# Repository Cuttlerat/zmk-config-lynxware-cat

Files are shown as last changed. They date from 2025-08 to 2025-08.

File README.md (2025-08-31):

# Lynxware Cat
[Lynxware Cat](https://www.lynxware.org/) is an open-source input device designed for creating flexible and customizable control solutions, supporting keyboard, mouse, joystick, and gyroscope interfaces.

This repository contains a modified build of Lynxware Cat v0.30.

Summary of notable changes:
- Added wireless communication using Nordic ESB via dongle.
- Migrated hardware target from BPI Leaf to Nordic nRF52840 (Nice!Nano v2 clone).
- Replaced mouse sensor with PMW3610.
- Ported firmware to ZMK.

For the complete list of changes, see the [CHANGELOG](./docs/CHANGELOG.md).

## Images

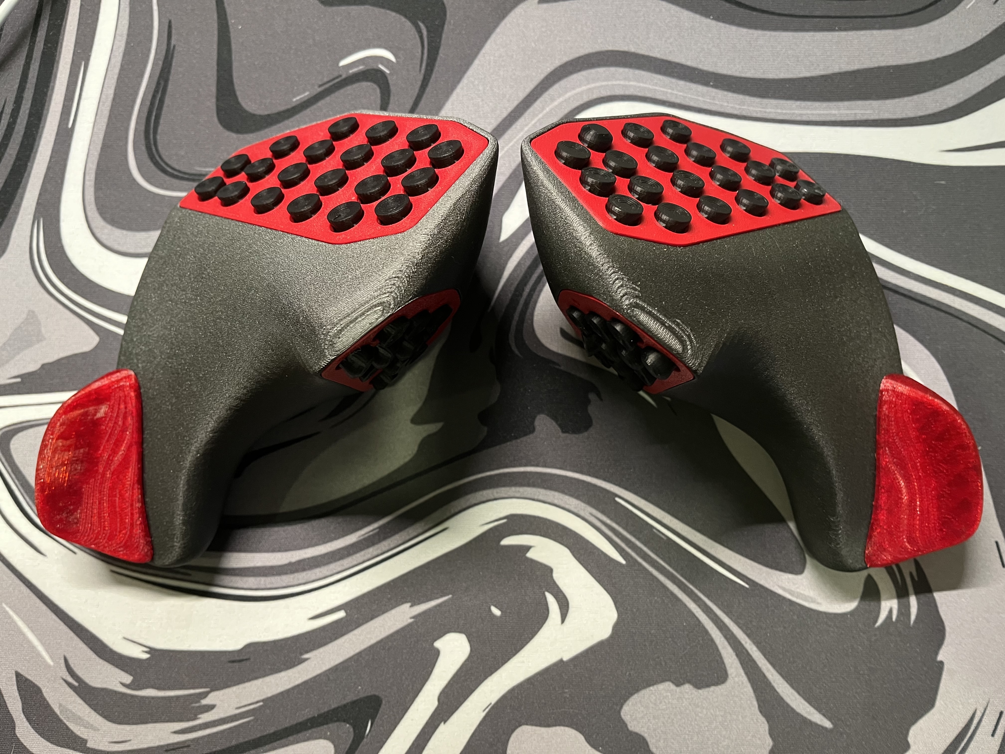
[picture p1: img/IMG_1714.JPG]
Lynxware Cat


More images are available in the [img](./img) directory.

## Keymap

<details>
<summary>Default layer</summary>

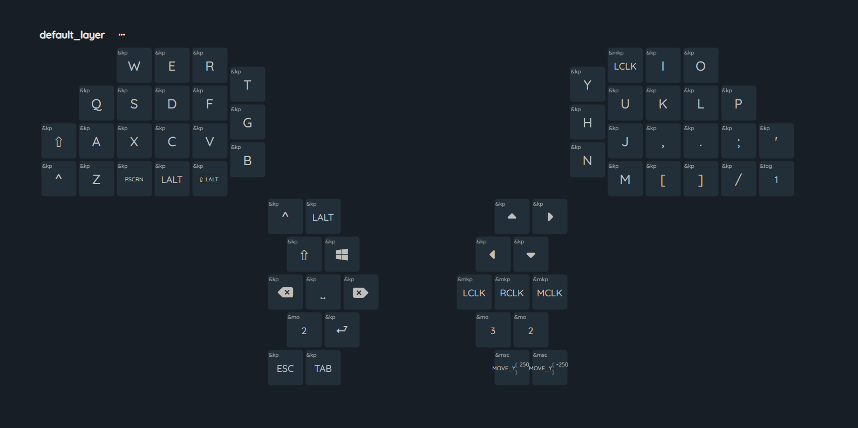
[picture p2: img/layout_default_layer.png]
Default layer


</details>

<details>
<summary>Numbers layer</summary>

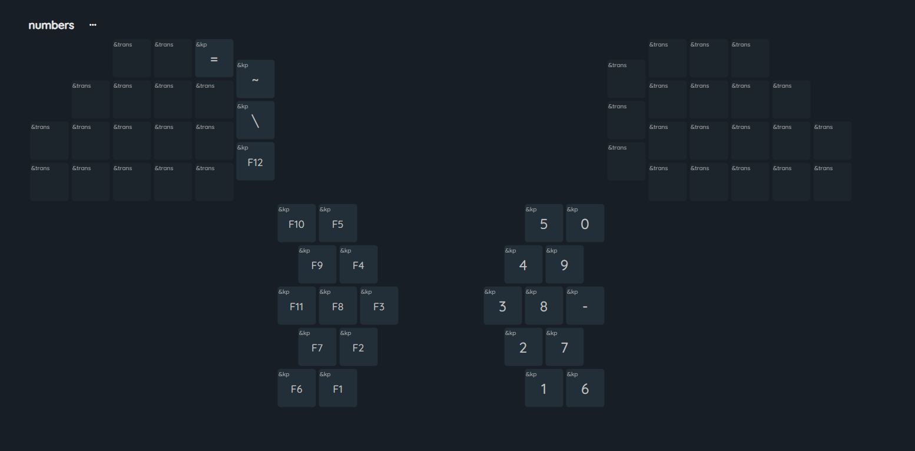
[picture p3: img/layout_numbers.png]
Numbers layer


</details>

<details>
<summary>Gaming layer</summary>

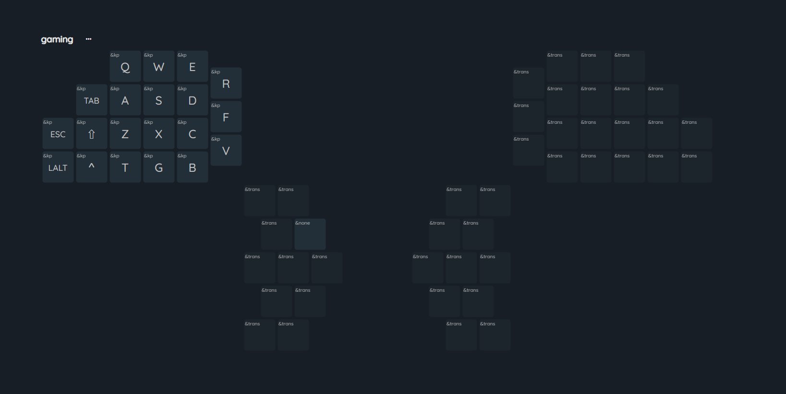
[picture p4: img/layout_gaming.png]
Gaming layer


</details>

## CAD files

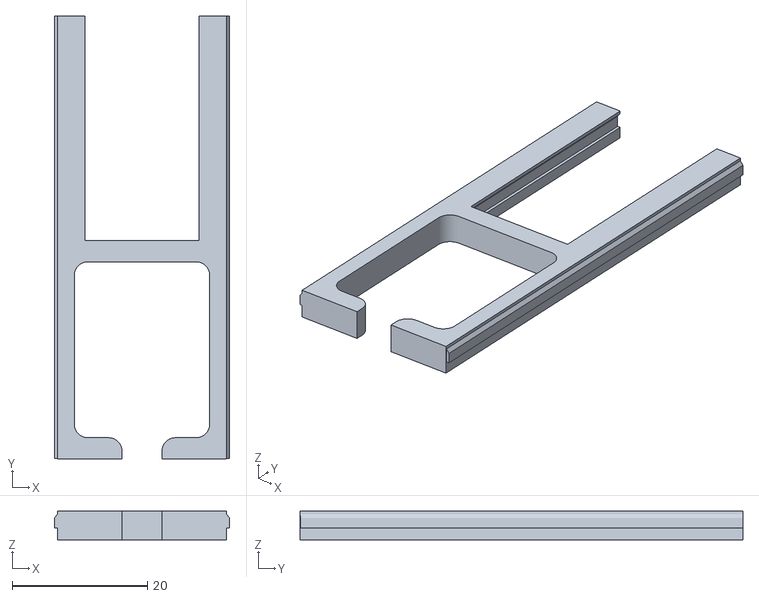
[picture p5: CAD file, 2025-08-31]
stl/lid-nrf52840-slider.stl
25.9 x 65.5 x 4.23

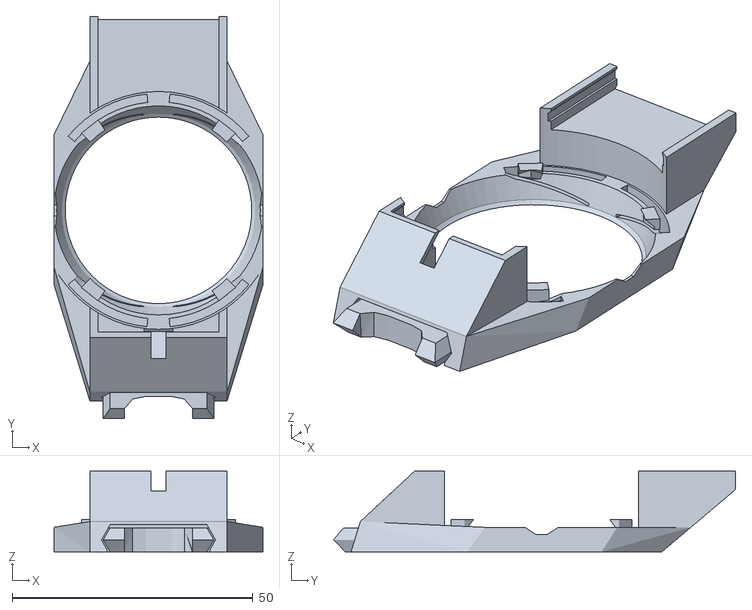
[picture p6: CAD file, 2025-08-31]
stl/lid-mouse.stl
43.4 x 83.5 x 16.8

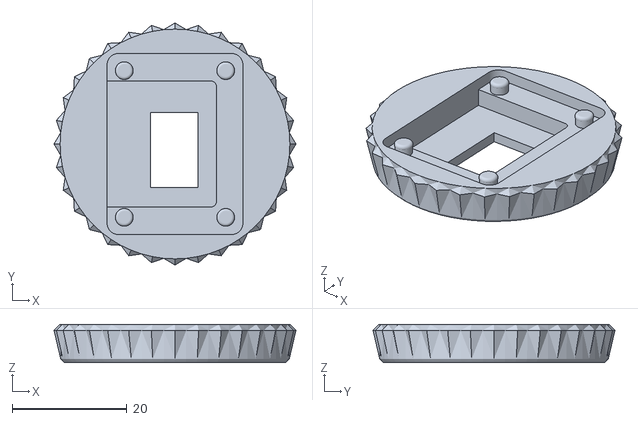
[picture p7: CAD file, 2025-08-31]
stl/pmw3610.stl
42.2 x 42.2 x 6.70

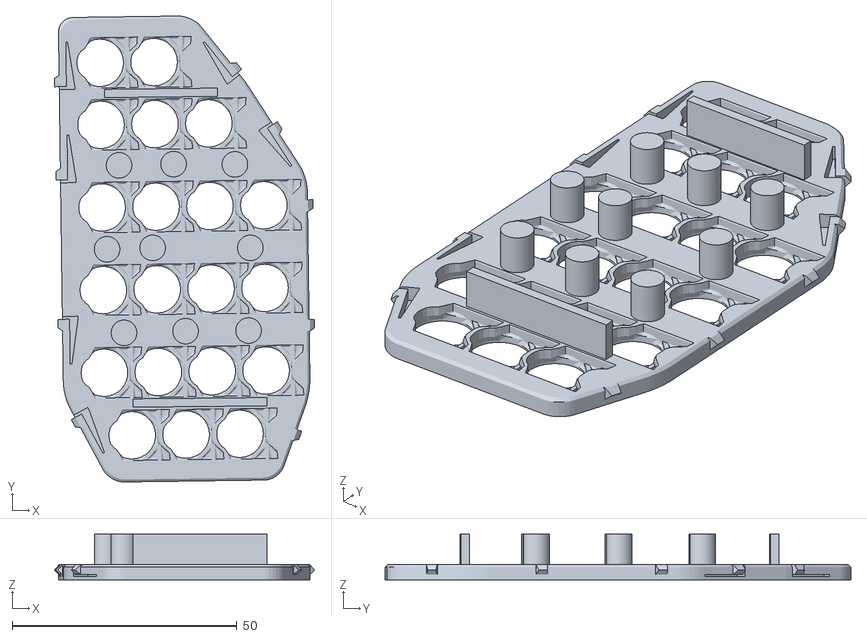
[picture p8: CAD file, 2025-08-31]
stl/front_cover.stl
57.9 x 103.7 x 10.2

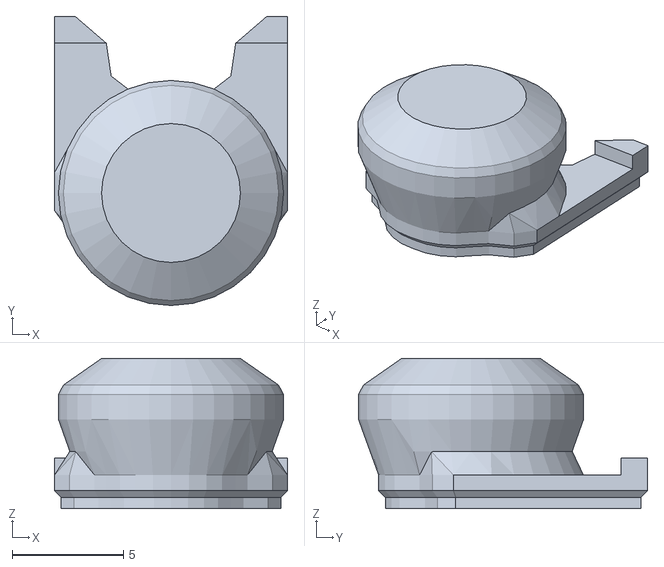
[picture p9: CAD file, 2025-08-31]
stl/button_O.stl
10.5 x 13.0 x 6.73

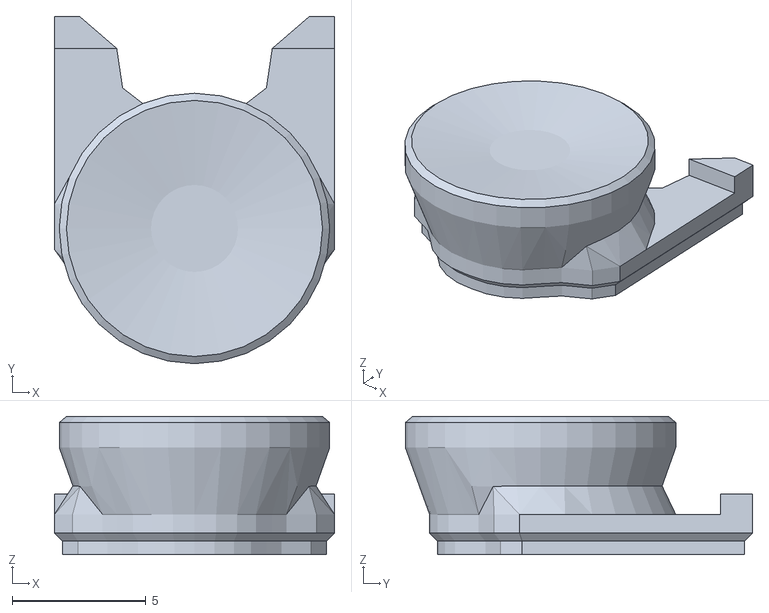
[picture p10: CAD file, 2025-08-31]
stl/button.stl
10.5 x 13.0 x 5.16

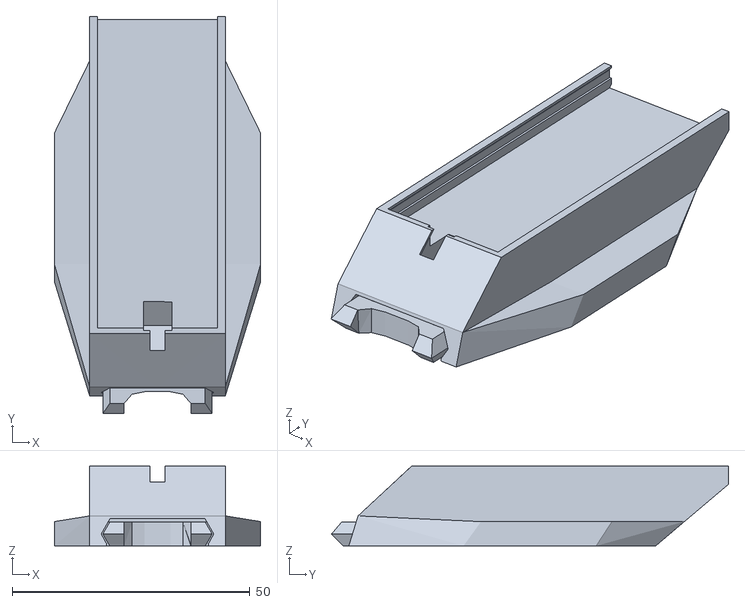
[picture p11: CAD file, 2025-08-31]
stl/lid.stl
43.4 x 83.5 x 16.8

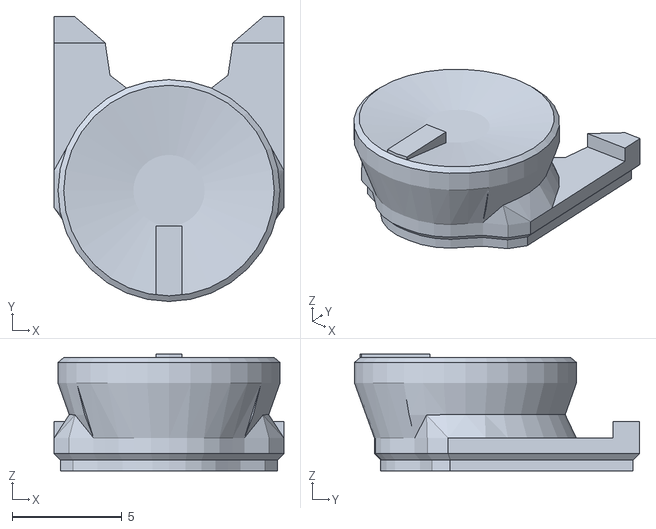
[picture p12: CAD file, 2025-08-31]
stl/button_I.stl
10.5 x 13.0 x 5.32

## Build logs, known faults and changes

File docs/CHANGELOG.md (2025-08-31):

# Overview
This project ports the Lynxware Cat to ZMK and makes it wireless. It also experiments with Kailh Mute switches and replaces the mouse sensor with PMW3610. Some 3D models were modified to accommodate the new hardware, the updated models are available in the [STL directory](../stl).
 
_This changelog lists only differences from the main DIY manual. For baseline instructions, see the [Lynxware DIY manual](https://www.lynxware.org/diy)._ 

## Full changelog
- Used ZMK instead of Lynxware Cat default firmware
- Wireless via Nordic ESB and dedicated dongle
  - Dongle acts as the central and listens for input events.
- Hardware migration and sensor integration
  - Target board migrated to `nice_nano_v2` (nRF52840).
  - Mouse sensor changed to PMW3610.
  - JST-XH 2.54 instead of DuPont connectors and pins.
  - No LEDs due to insufficient pins on the nRF board.
- Switches and mechanics
  - Kailh Mute switches evaluated for quieter actuation and reduced noise.
  - Plate/keycap tolerances adjusted.
- 3D model updates
  - Modifications to fit Nice!Nano v2, PMW3610 PCB, and ESB dongle.
  - Added spacers on front and thumb panels to ensure clearance between panel and PCB.
  - Buttons with increased tolerances.
- Mouse skates changed to a modern gaming type (6 mm diameter), mounted to the case bottom (not into skate/pad pockets)

## Bill of Materials (only changes)

| Item | Change | Specification | Qty | Notes | Links |
| --- | --- | --- | --- | --- | --- |
| Controller | Replace default controller with Nice!Nano v2; add dedicated dongle | Nice!Nano v2 (nRF52840) or compatible | 3 | | |
| Batteries | Add per-side Li-ion battery | Li-ion 102530 800 mAh | 2 |  | |
| JST connectors | Use JST-XH 2.54 instead of DuPont | 2x4-pin, 2x6-pin, 2x10-pin |  |  | |
| Mouse sensor | Replace mouse sensor with PMW3610 | PMW3610 PCB | 1 |  | [PMW3610 PCB](https://github.com/siderakb/pmw3610-pcb) |
| Switches | Use Kailh Mute switches | Kailh Mute | 64 | 62 for default buttons and 2 for reset buttons | |
| Mouse skates | Use modern gaming skates mounted to case bottom | 6 mm diameter | 10 | Mounted to case bottom; not into skate/pad pockets | |
| Case parts | Modify 3D-printed case/plates (spacers, tolerances) | 3D-printed | set |  | [STL directory](../stl) |

## Pinout 

<details>
<summary>Thumb cluster (buttons)</summary>

| Name | Pin |
| --- | --- |
| Ti4 | P0.31 |
| Ti3 | P0.29 |
| Ti2 | P0.02 |
| Ti1 | P1.15 |
| To3 | P1.13 |
| To2 | P1.11 |
| To1 | P0.10 |

</details>

<details>
<summary>Gamepad (WIP)</summary>

| Name | Pin |
| --- | --- |
| JV | P0.31 |
| JY | P0.29 |
| JX | P0.02 |
| Ti2 | P1.15 |
| Ti1 | P1.13 |
| To3 | P1.11 |
| To2 | P0.10 |
| To1 | P0.06 |

</details>

<details>
<summary>Front panel - Right</summary>

| Name | Pin |
| --- | --- |
| Fi1 | P0.09 |
| Fi2 | P1.07 |
| Fi3 | P1.02 |
| Fi4 | P1.01 |
| Fo1 | P1.06 |
| Fo2 | P1.04 |
| Fo3 | P0.11 |
| Fo4 | P1.00 |
| Fo5 | P0.24 |
| Fo6 | P0.08 |

</details>

<details>
<summary>Front panel - Left</summary>

| Name | Pin |
| --- | --- |
| Fi1 | P0.09 |
| Fi2 | P1.07 |
| Fi3 | P1.02 |
| Fi4 | P1.01 |
| Fo6 | P1.06 |
| Fo5 | P1.04 |
| Fo4 | P0.11 |
| Fo3 | P1.00 |
| Fo2 | P0.24 |
| Fo1 | P0.08 |

</details>

<details>
<summary>Mouse Sensor</summary>

| Signal | Pin |
| --- | --- |
| SCK | P0.17 |
| MOSI | P0.20 |
| MISO | P0.20 |
| CS | P0.06 |
| IRQ | P0.22 |

</details>

## 3D printing
**Printer**: Bambu Lab P1S

| Part | Material | Nozzle | Layer height | Notes |
| --- | --- | --- | --- | --- |
| Case | ERYONE PETG-CF Black | 0.4 mm hardened | 0.2 mm | Cheaper alternative to Bambu Lab PETG-CF |
| Buttons | Bambu Lab PETG-HF Black | 0.4 mm hardened | 0.08 mm | |
| Other parts | Bambu Lab PLA Maroon Red | 0.4 mm hardened | 0.2 mm | |

## Known issues
- Button keycaps are not secure and can be jiggly; consider shimming or alternative keycaps.
- Some buttons can stick and repeat due to ESB transport behavior; pressing the dongle's reset button resolves it.

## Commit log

2025-08-15 fix: enable USB logging snippet for nice_nano_v2 board
2025-08-27 fix: enable zmk-usb-logging snippet for Lynxware Cat boards
2025-08-31 docs: update README with project description and notable changes
    [button.stl, button_I.stl, button_O.stl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]
2025-09-01 fix: update retransmission count and add battery reporting configurations in lynxware_cat.conf
2025-09-01 fix: enable battery reporting for split central in lynxware_cat_dongle.conf
2025-09-02 feat: add SSD1306 display support and I2C configuration for lynxware_cat_dongle
2025-09-02 fix: correct syntax in lynxware_cat_dongle.overlay for I2C configuration
2025-09-02 fix: enable zmk-usb-logging snippet in build.yaml and correct SSD1306 I2C address in lynxware_cat_dongle.overlay
2025-09-02 fix: update I2C configuration for lynxware_cat_dongle.overlay to correct pin assignments
2025-09-02 refactor: clean up I2C configuration in lynxware_cat_dongle.overlay by removing redundant options
2025-09-02 feat: add I2C and LVGL configurations to lynxware Kconfig.defconfig for enhanced display support
2025-09-02 refactor: streamline Kconfig.defconfig for lynxware by organizing display and I2C configurations
2025-09-02 feat: add additional ZMK widget configurations for battery and output status in lynxware_cat_dongle.conf
2025-09-02 fix: disable local battery reporting for lynxware_cat_dongle and enable it for lynxware_cat
2025-09-02 feat: enable battery percentage display in lynxware_cat_dongle configuration
2025-09-02 fix: enable battery reporting in lynxware_cat_dongle configuration to meet widget dependencies
